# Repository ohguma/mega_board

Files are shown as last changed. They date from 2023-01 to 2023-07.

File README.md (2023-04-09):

# Arduino Mega 拡張基板

## 概要

+ Arduino Mega のA0～15をXHコネクタで使うための基板。別途下記の利用も可能。
  + 4ピンXHで［D29,D31］［D33,D35］［D37,D39］［D41,D43］
  + 他のデジタルピンもビアから接続可能。
  + 3つのスイッチ（D51,D52,D53） INPUT_PULLUPで利用する。
  + 3つのLED（D45,D47,D49）　HIGHで点灯。
  + サーボ用端子（D10～13）　電源をバッテリー直結かレギュレータ経由か切り替え可能
  + 複数のI2C端子
    + TJ3B互換［SCL,5V,SDA,GND］を2ポート
    + MPU6050用
    + [AE-BNO055-BO](https://akizukidenshi.com/catalog/g/gK-16996)
    + OLED(128x32)
+ モータードライバTB67H450FNGを最大４個搭載可能。
  + [TB67H450FNG日本語データシート](https://toshiba.semicon-storage.com/info/TB67H450FNG_datasheet_ja_20201126.pdf?did=65345&prodName=TB67H450FNG)
  + 1ch：D2,D3　2ch：D4,D5　3ch：D6,D7　4ch：D8,D9
+ 各XHコネクタへの電源は、Mega 内蔵とは別のレギュレータから供給する。ジャンパ接続で内蔵5Vも利用可能。
+ レギュレータを3.3Vに変更することで Arduino Due でも利用可能。
+ 基板サイズ　98 x 98mm、周囲の穴は3.2mm径、5mm間隔
  + [タミヤ ユニバーサルプレート](https://www.tamiya.com/japan/products/70172/index.html)上に取り付け可能。
  
----
## サンプルスケッチ

+ [sample/](./sample/)  

## マニュアル
+ [Arduino Mega 2560 基板(秋月 TB67H450FNG)マニュアル](./documents/robot_arduino_mega202210_AE-TB67H450_manual.pdf) 2022-10
+ [Arduino Mega 2560 基板(Poloru BD65496MUV)マニュアル](./documents/robot_arduino_mega202203_BD65496MUV_manual.pdf) 2022-04
  - TB67H450以前バージョン。モータードライバの配線は同様なので、同じスケッチが動作する。
  - LED1,2,3が基板パターンに実装されていないのでユニバーサル基板部分に追加すること。 
  - [BD65496MUV Single Brushed DC Motor Driver Carrier](https://www.pololu.com/product/2960)

## 実装例

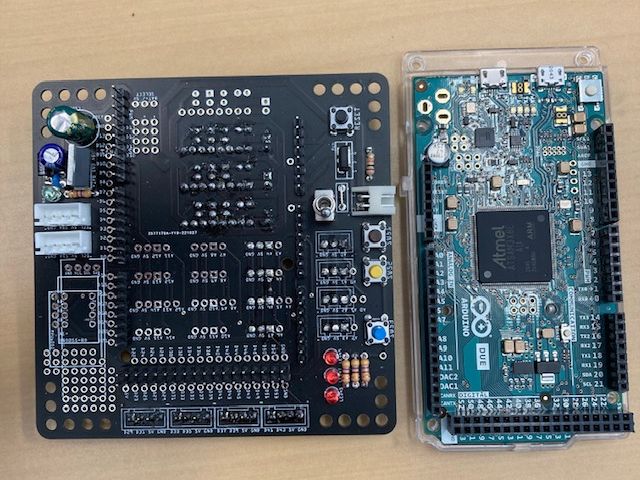
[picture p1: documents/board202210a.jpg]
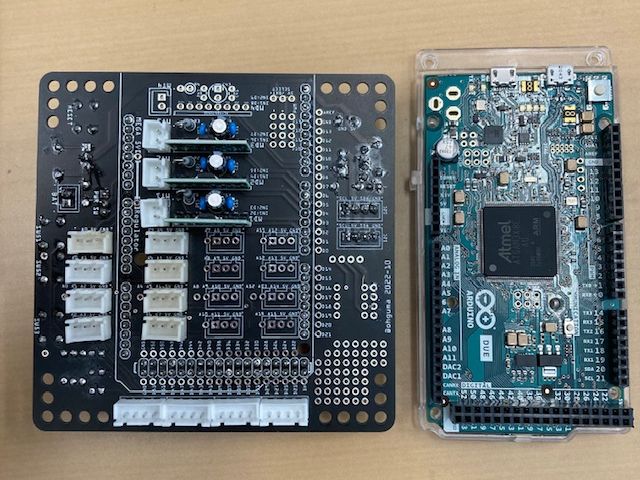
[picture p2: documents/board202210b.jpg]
　

----
### パーツリスト

個数は明記なければ1個。

+ Arduino Mega2560 R3　もしくは　Arduino Due　もしくはそれらの互換機
+ ピンヘッダ
  - 1x8　5個
  - 1x10　10個
  - 2x18　18個
  - 1x3　最大4個。サーボ使用時
+ 入出力 
  - LED45,47,49用3mmLED
  - 上記LED用電流制限抵抗 1KΩ（茶黒赤金　Vf=2[V]3mA想定）
  - タクトスイッチ　制御用　3個
  - タクトスイッチ　リセット用　1個
  - （任意）[秋月　ＢＮＯ０５５使用　９軸センサーフュージョンモジュールキット AE-BNO055-BO](https://akizukidenshi.com/catalog/g/gK-16996)
    - VIN、GND、SDA/T、SCL/Rを接続する。
  - （任意）ジャイロセンサMPU-6050
    - amazon などでMPU6050(GY-521)として売られているもの。
    - VCC、GND、SCL、SDAの4ピンを接続する。 
  - （任意）OLED 128x32 I2C
    - Adafruit SSD1306 ライブラリを利用する。

+ モータードライバ関係　最大4セット
  - [秋月　ＴＢ６７Ｈ４５０モータドライバモジュール AE-TB67H450](https://akizukidenshi.com/catalog/g/gK-14753/)
  
    - [マルツ　ブラシ付きDCモータードライバーIC DIP化基板(TB67H450FNG)](https://www.marutsu.co.jp/pc/i/1559301/)も同じピン配置なので利用できると思われる。
  - 金属皮膜抵抗 1W 0.2Ω　　抵抗値の選定はTB67H450データシート参照のこと。
  - 電解コンデンサ 50V 100uF
  - セラミックコンデンサ 0.1uF （104）
    - セラミックコンデンサのみ1セット中2個、他は1個づつ
+ 電源関連 各1個
  - 基板用トグルスイッチ（下記FETのON/OFF用）
  - PchパワーMOSFET（30V40A MTP4835I3等）
  - 抵抗 10KΩ（茶黒橙金）
  - ポリスイッチ　　短絡等の保護用。不要時はジャンパ接続する。
+ センサ系電源まわり
  - ショットキーダイオード （40V1A 1S4など。レギュレータへの逆接防止用）
  - ５Vレギュレータ（5V1A TA4805S等）　※Due使用時は3.3Vレギュレータ使用
  - セラミックコンデンサ 0.1uF （104）
  - 電解コンデンサ 50V 100uF
  - 電源ON表示用3mmLED
  - 上記LED用電流制限抵抗 1KΩ（茶黒赤金　Vf=2[V]想定で3mA）
  - 電解コンデンサ 10V 1000uF等

## 購入先

+ パーツは[秋月電子](https://akizukidenshi.com/catalog/)で概ね揃う。
+ 2023年1月21日時点、Due は[アスクル](https://www.askul.co.jp/p/KA08233/)が安い。（ピンヘッダなしが3,950円）

----
## 回路図

- モータードライバ周りはアプリケーションノートに従った。
  - [TB67H450FNGアプリケーションノート](https://akizukidenshi.com/download/ds/toshiba/TB67H450FNG_application_note_ja_20190510.pdf)

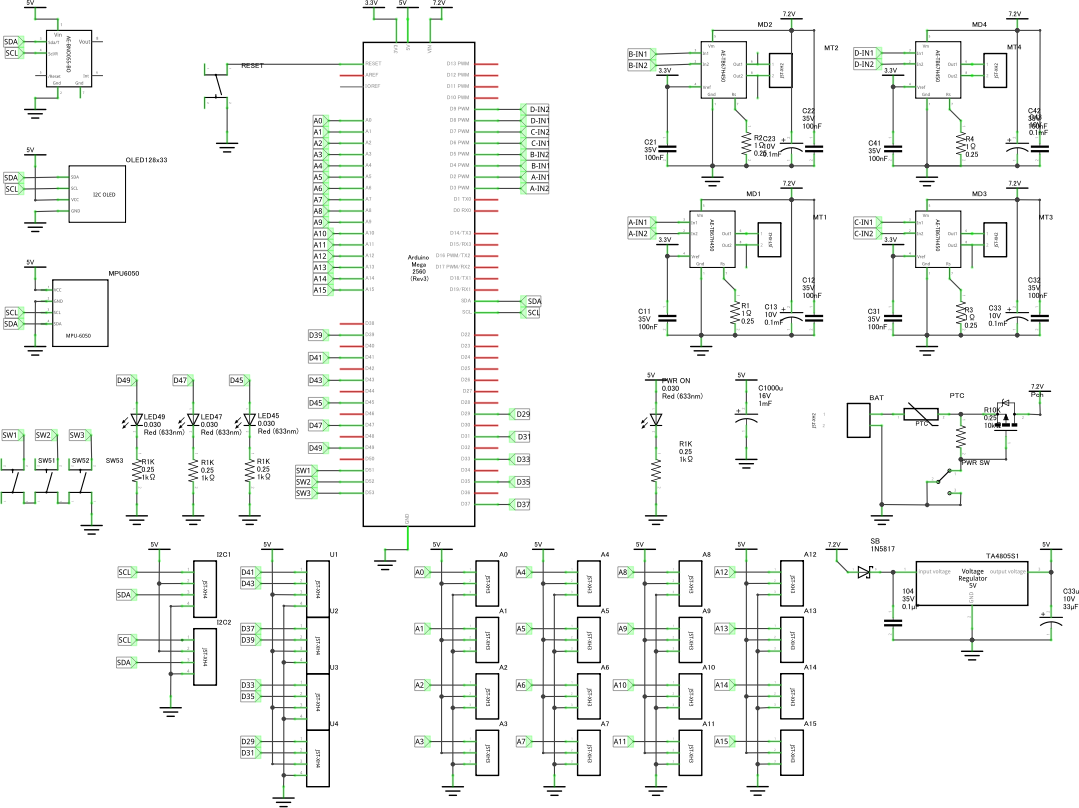
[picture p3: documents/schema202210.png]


----
## 基板作成

+ [Fritzing](https://fritzing.org/)で設計し、基板作成まで行った。
  + コネクタは表・裏どちらにも実装し易いよう、両面にシルクを入れた。（裏面はSVGを貼り付け）
  + 参考書　 「[Fritzing入門実習テキスト「Fritzing Basics」#マッハ新書 （ダウンロード商品）](https://booth.pm/ja/items/1414214)」
+ 基板作成は「[JLCPCB](https://jlcpcb.com/)」を利用した。
  + つや消し黒が安い。
  + 2022-10-27発注、2022-11-09、到着運送便はOCS Expressを選択（配達は佐川急便だった）
  + twitter https://twitter.com/JLCPCB_Japan
+ [発注時ガーバーファイル](./pcb/robot_arduino_mega202210_AE-TB67H450.zip)

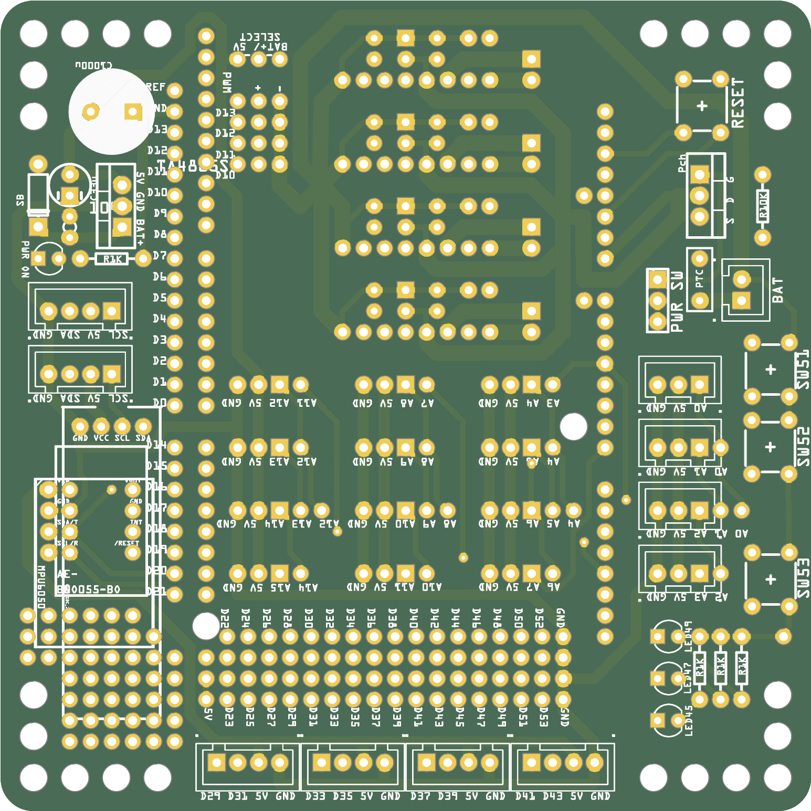
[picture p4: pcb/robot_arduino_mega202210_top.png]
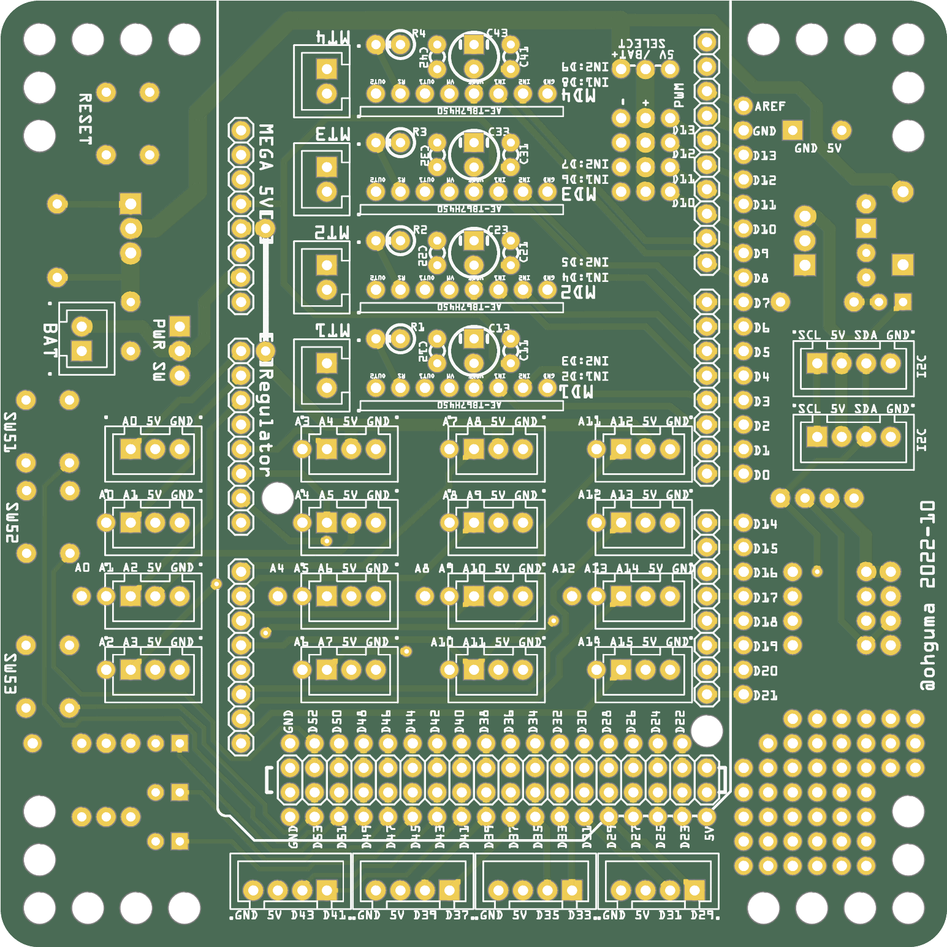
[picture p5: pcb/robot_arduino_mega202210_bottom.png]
 

----
## 3Dプリントデータ
+ [Arduino Mega 底面ホルダ](./cad/mega_bottom.stl)　※ホルダが付属しない互換機などでの利用を想定。

----

2023-04-09 ohguma 内容補足、マニュアル・サンプル追加
2023-01-21 ohguma 初版

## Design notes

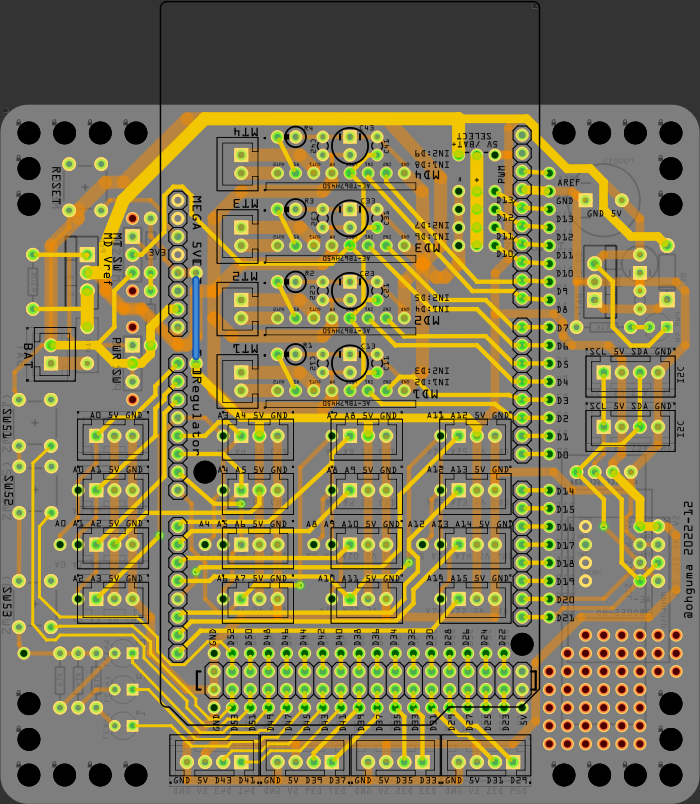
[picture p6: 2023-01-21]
documents/pcb202212b.png

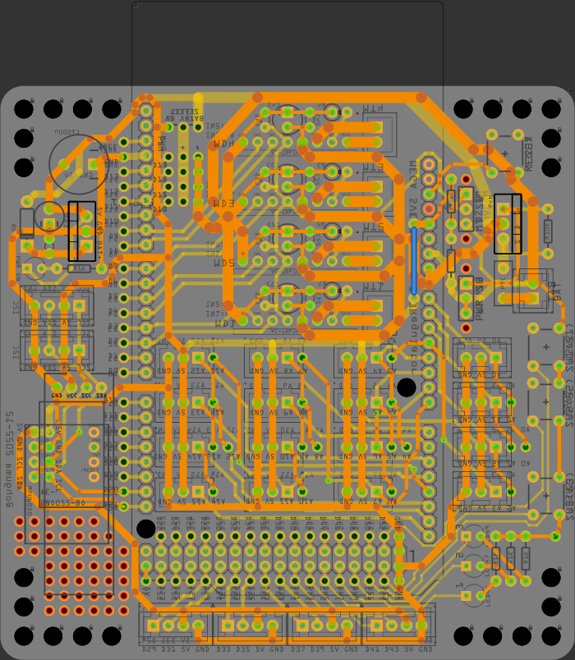
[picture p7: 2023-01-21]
documents/pcb202212a.png

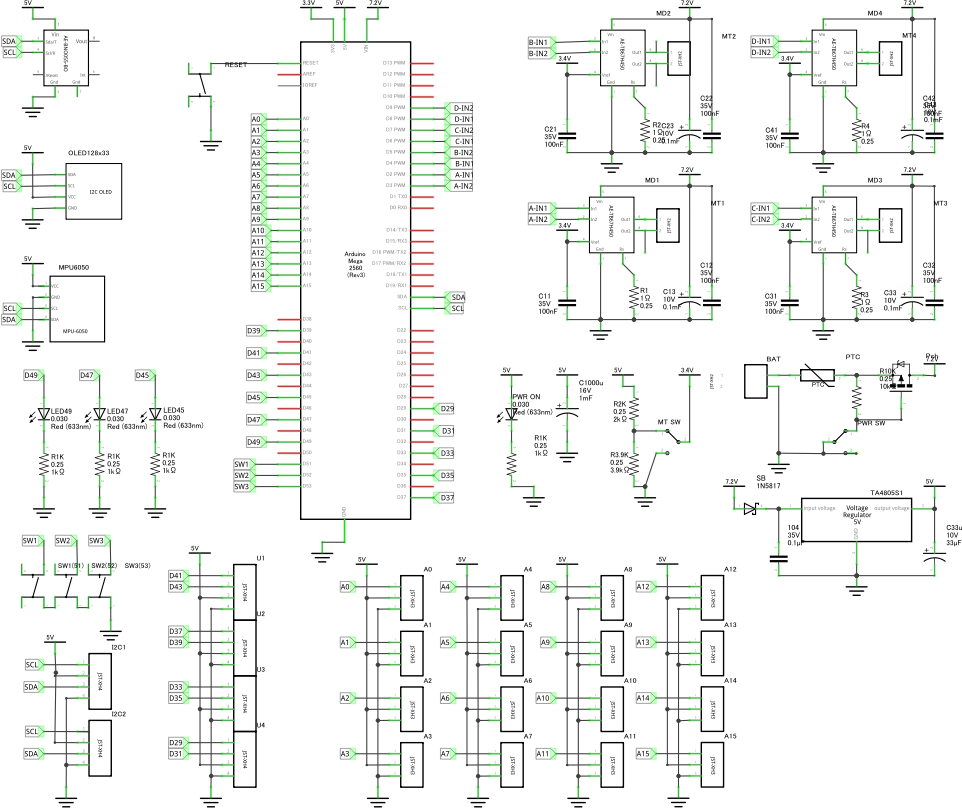
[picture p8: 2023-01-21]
documents/schema202212.png

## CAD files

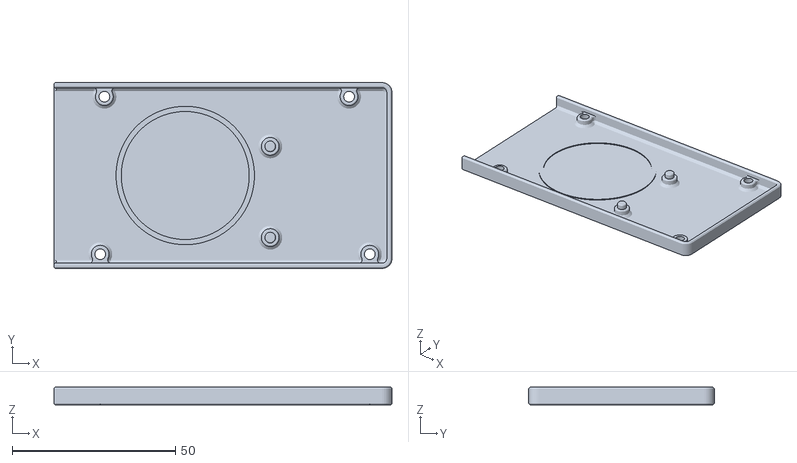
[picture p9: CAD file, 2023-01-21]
cad/mega_bottom.stl
103.5 x 56.9 x 5.40

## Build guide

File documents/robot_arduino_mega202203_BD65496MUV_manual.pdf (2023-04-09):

### ■Arduino Mega 2560 基板(Poloru BD65496MUV)

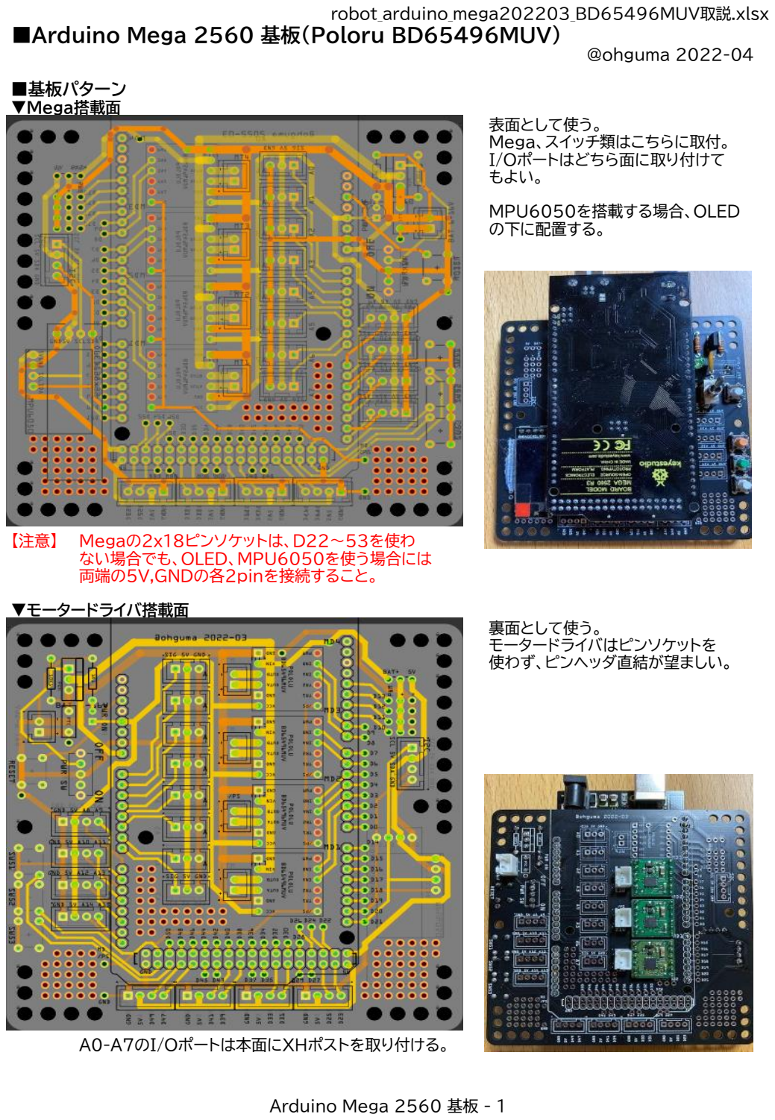
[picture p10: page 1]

robot_arduino_mega202203_BD65496MUV取説.xlsx

@ohguma 2022-04

■基板パターン
▼Mega搭載面
表面として使う。
Mega、スイッチ類はこちらに取付。
I/Oポートはどちら面に取り付けて
もよい。

MPU6050を搭載する場合、OLED
の下に配置する。

【注意】 Megaの2x18ピンソケットは、D22～53を使わ ない場合でも、OLED、MPU6050を使う場合には 両端の5V,GNDの各2pinを接続すること。

▼モータードライバ搭載面
裏面として使う。
モータードライバはピンソケットを
使わず、ピンヘッダ直結が望ましい。

A0-A7のI/Oポートは本面にXHポストを取り付ける。

Arduino Mega 2560 基板 - 1 robot_arduino_mega202203_BD65496MUV取説.xlsx ■回路図

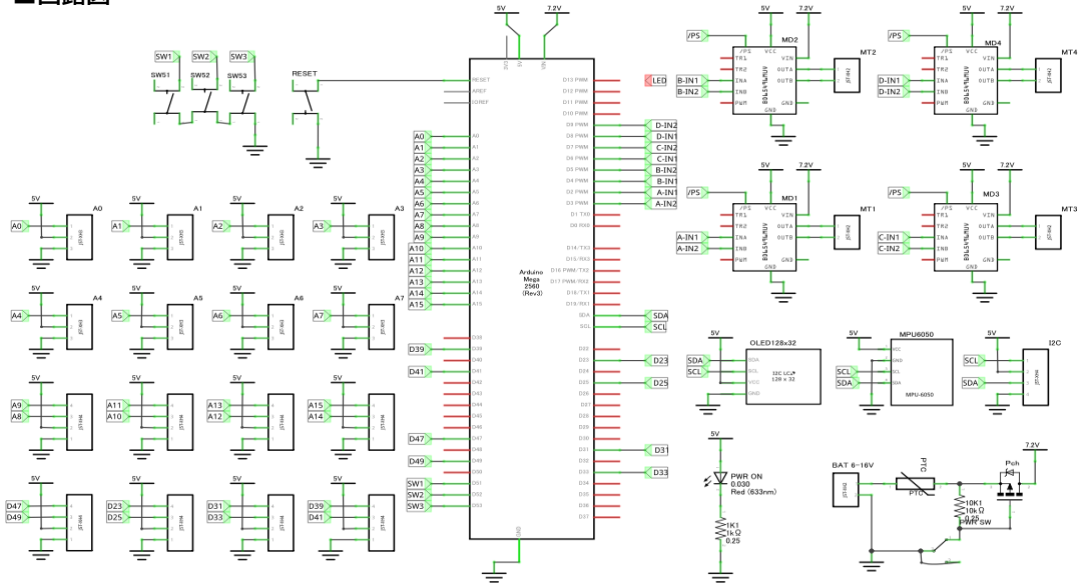
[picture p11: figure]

■パーツリスト
No | 品名 | 数量
1 | Arduino Mega2560　R3、もしくは互換機 | 1
2 | Pololu BD65496MUV Single Brushed DC Motor Driver Carrier | 最大4
3 | ジャイロセンサMPU-6050 任意 | 1
4 | OLED 128x32 I2C 任意 | 1
5 | 基板用トグルスイッチ | 1
6 | ポリスイッチ | 1
7 | PchパワーMOSFET | 1
8 | 抵抗 10KΩ | 1
9 | 電源ON表示用LED | 1
10 | その電流制限用抵抗 | 1
11 | タクトスイッチ　制御用 x3、リセット用 x1 | 4
12 | ピンヘッダ1x10 | 1
13 | ピンヘッダ1x8 | 5
14 | ピンヘッダ2x18　（D22～53を使わない場合不要だが、OLED等使用時は注意） | 1
15 | XH2ピン用ベース付ポスト 任意
16 | XH3ピン用ベース付ポスト 任意
17 | XH4ピン用ベース付ポスト 任意

■予約ピンなど
D５１ | SW51 | pinMode(５1, INPUT_PULLUP)で使う。押したときLOW
D５２ | SW52 | pinMode(５2, INPUT_PULLUP)で使う。押したときLOW
D５３ | SW53 | pinMode(５3, INPUT_PULLUP)で使う。押したときLOW
D2,3 | MD1のINA,INB
D4,5 | MD2のINA,INB
D6,7 | MD3のINA,INB
D8,9 | MD4のINA,INB

OLEDはライブラリ「Adafruit_SSD1306」の例「ssd1306_128x32_i2c」を流用

ー　以上　ー

Arduino Mega 2560 基板 - 2

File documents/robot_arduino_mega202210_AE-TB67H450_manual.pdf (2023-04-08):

### ■Arduino Mega 2560 基板(秋月 TB67H450FNG)

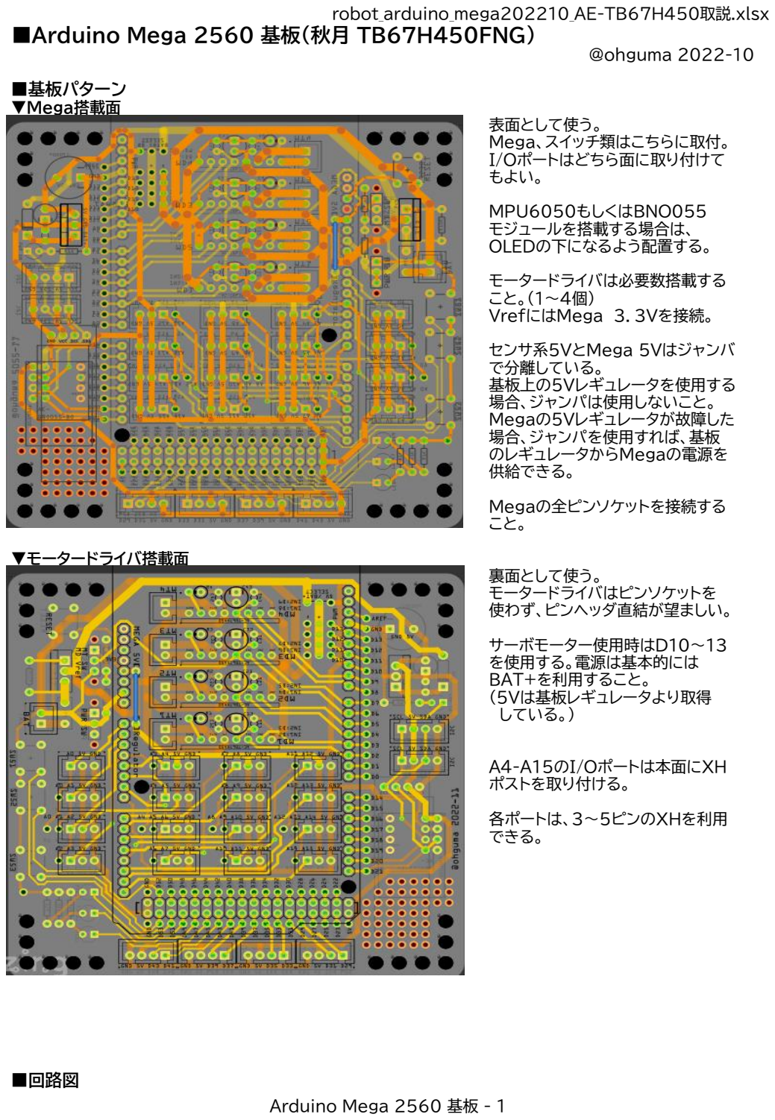
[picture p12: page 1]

robot_arduino_mega202210_AE-TB67H450取説.xlsx

@ohguma 2022-10

■基板パターン
▼Mega搭載面
表面として使う。
Mega、スイッチ類はこちらに取付。
I/Oポートはどちら面に取り付けて
もよい。

MPU6050もしくはBNO055
モジュールを搭載する場合は、
OLEDの下になるよう配置する。

モータードライバは必要数搭載する
こと。（1～4個）
VrefにはMega　３．３Vを接続。

センサ系5VとMega 5Vはジャンバ
で分離している。
基板上の5Vレギュレータを使用する
場合、ジャンパは使用しないこと。
Megaの5Vレギュレータが故障した
場合、ジャンパを使用すれば、基板
のレギュレータからMegaの電源を
供給できる。

Megaの全ピンソケットを接続する
こと。

▼モータードライバ搭載面
裏面として使う。
モータードライバはピンソケットを
使わず、ピンヘッダ直結が望ましい。

サーボモーター使用時はD10～13
を使用する。電源は基本的には
BAT+を利用すること。
(5Vは基板レギュレータより取得
している。）

A4-A15のI/Oポートは本面にXH
ポストを取り付ける。

各ポートは、３～5ピンのXHを利用
できる。

■回路図
Arduino Mega 2560 基板 - 1

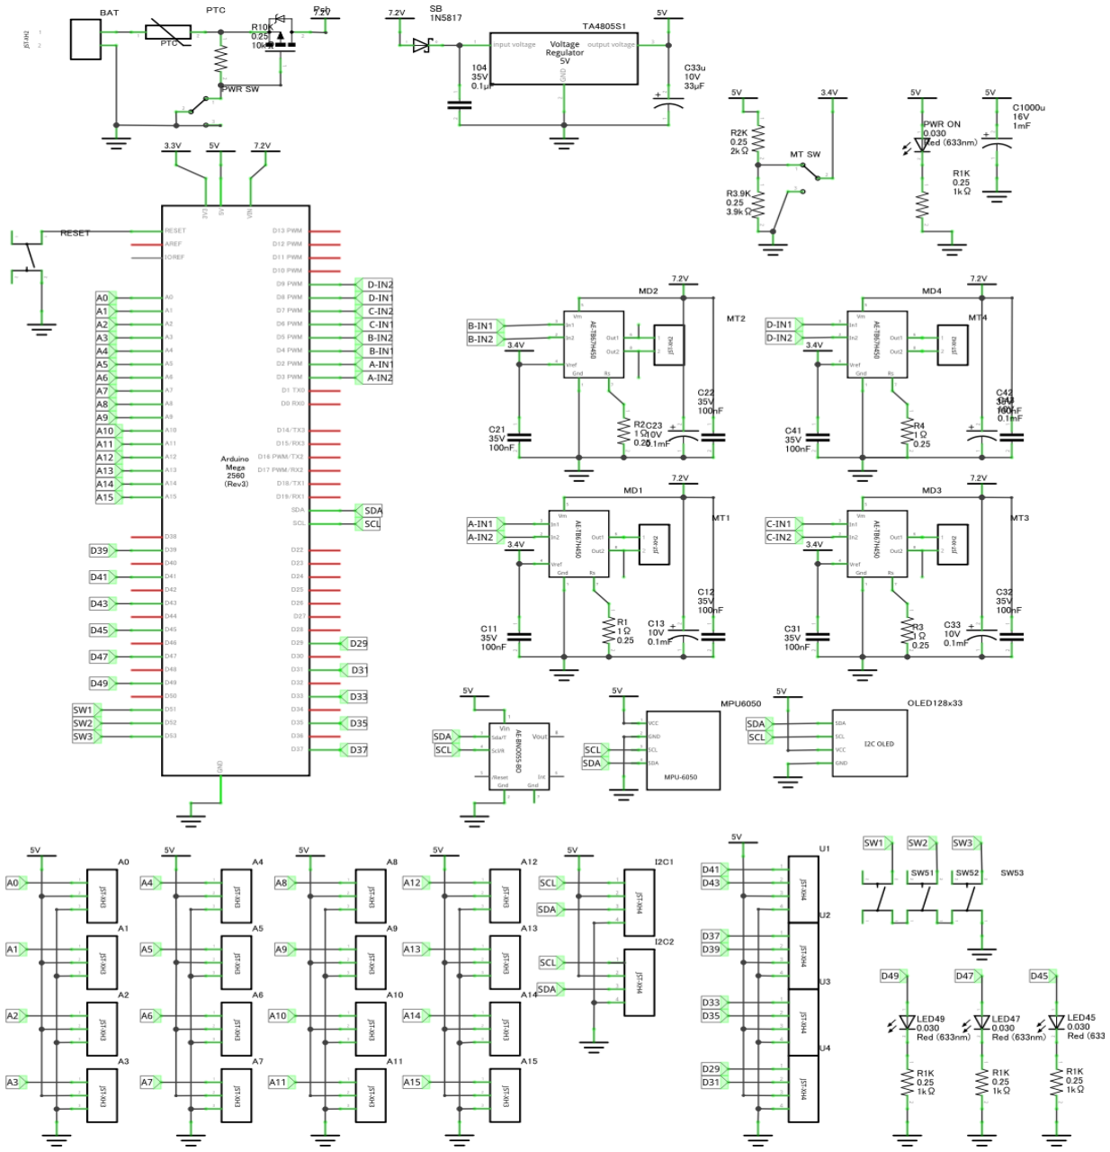
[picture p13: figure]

■パーツリスト
No | 品名 | 数量

1 | Arduino Mega2560　R3、もしくは互換機 | 1
2 | ピンヘッダ 1x8 | 5
3 | ピンヘッダ 1x10 | 1
4 | ピンヘッダ 2x18 | 1
| 【モータードライバ関係　最大4セット】
5 | 秋月　ＴＢ６７Ｈ４５０モータドライバモジュール 数量は1セットあたり | 1
6 | 金属皮膜抵抗 1W 0.2Ω | 1
7 | セラミックコンデンサ 0.1uF (104） | 2
8 | 電解コンデンサ 50V 100uF | 1
| 【センサ、表示機】　任意
9 | 秋月　ＢＮＯ０５５使用　９軸センサーフュージョンモジュールキット 任意 | 1
10 | ジャイロセンサMPU-6050 任意 | 1
11 | OLED 128x32 I2C 任意 | 1
12 | LED45,47,49用3mmLED | 3
13 | 上記LED用電流制限抵抗 1KΩ（茶黒赤金　Vf=2[V]想定で３ｍA） | 3
14 | タクトスイッチ　制御用 x3、リセット用 x1 | 4
| 【電源まわり】
15 | 基板用トグルスイッチ（下記FETのON/OFF用） | 1
16 | PchパワーMOSFET（30V40A MTP4835I3等） | 1
17 | 抵抗 10KΩ（茶黒橙金） | 1
18 | ポリスイッチ ない場合はリード線で直結 | 1
| 【センサ系電源まわり】
19 | ショットキーダイオード （４０V1A 1S4など。レギュレータへの逆接防止用） | 1
20 | ５Vレギュレータ（5V1A TA4805S等） ※DUE使用時は3.3V | 1
21 | セラミックコンデンサ 0.1uF (104） レギュレータに合わせる。入力側 | 1
22 | 電解コンデンサ 50V 100uF レギュレータに合わせる。出力側 | 1
23 | 電源ON表示用3mmLED | 1
24 | 上記LED用電流制限抵抗 1KΩ（茶黒赤金　Vf=2[V]想定で3mA） | 1
25 | 電解コンデンサ 10V 1000uF等 センサ電源の安定化用 | 1
| 【コネクタ類】
26 | XH2ピン用ベース付ポスト（バッテリ接続、モーター接続用） 任意
27 | XH3ピン用ベース付ポスト 任意
28 | XH4ピン用ベース付ポスト 任意
※レギュレータを3.3Vにする場合、LED用電流制限抵抗は470Ω等適宜調整する。

■予約ピンなど
D５１ | SW51 | pinMode(５1, INPUT_PULLUP)で使う。押したときLOW
D５２ | SW52 | pinMode(５2, INPUT_PULLUP)で使う。押したときLOW
D５３ | SW53 | pinMode(５3, INPUT_PULLUP)で使う。押したときLOW
D45 | LED45 | pinMode(45, OUTPUT)で使う。
D47 | LED47 | pinMode(47, OUTPUT)で使う。
D49 | LED49 | pinMode(49, OUTPUT)で使う。
D2,3 | MD1のINA,INB
D4,5 | MD2のINA,INB
D6,7 | MD3のINA,INB
D8,9 | MD4のINA,INB
D10～13 | サーボコネクタ用パターンあり

OLEDはライブラリ「Adafruit_SSD1306」の例「ssd1306_128x32_i2c」を流用 ー　以上　ー

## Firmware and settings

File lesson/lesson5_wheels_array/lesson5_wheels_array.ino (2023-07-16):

//----------------------------
// LESSON5：ホイールを複数回す。配列の練習
//
// 2023-07-15 ohguma 初版
//----------------------------
// Arduino Mega 拡張基板
// https://github.com/ohguma/mega_board
//
// ■ピン設定
// モータードライバ TOSHIBA TB67H450FNG
// https://toshiba.semicon-storage.com/info/TB67H450FNG_datasheet_ja_20201126.pdf?did=65345&prodName=TB67H450FNG
//   IN1   IN2   OUT1  OUT2  動作
//   ----  ----  ----  ----  -----------------
//   0     0     OFF   OFF   停止（モーター端子が接続されていない状態）
//   数値  0     ＋    －    時計回り（OUT1が電源＋、OUT2が電源－に接続される）
//   0     数値  －    ＋    反時計回り（OUT2が電源＋、OUT1が電源－に接続される）
//   数値  数値  －    －    ショートブレーキ（モーター端子を短絡した状態）
//
// ※最大4つのモータードライバは、IN1/IN2 に Arduino Mega のそれぞれ以下を
//   接続している。
//     MT1  D2/D3
//     MT2  D4/D5
//     MT3  D6/D7
//     MT4  D8/D9
//
// ※モーターの＋端子に赤線、反対側には黒線をハンダ付けし、XHコネクタには電
//   池ボックスと同じ向きに赤線・黒線を差し込むこと。
//   （コネクタの▲マークに赤線を接続する。）
//   このとき、モータードライバのOUT1にモーターの＋端子、OUT2には反対側端子
//   が接続される。
//
// ※モーターは＋端子に電池のプラス、反対側にマイナスを接続すると、ギヤを取
//   り付ける側からモーターを見た場合に、通常モーター軸が時計回りする。
//   ギヤボックスを使う場合は内部のギヤの組み合わせにより、出力軸がモーター
//   軸とは逆に回る場合がある。
//
// ※Arduino Megaでは数値はanalogWrite()の0～255で指定する。
//   0を指定した時が0%、255を指定した時が100%。
//
const int NUM_MOTOR = 2;
const int PIN_IN1[NUM_MOTOR] = { 2, 4 };
const int PIN_IN2[NUM_MOTOR] = { 3, 5 };
// タクトスイッチ
// ・SW1,SW2,SW3：D51,D52,D53かから各SWを経由してGNDに接続。
// ・INPUT_PULLUPモードで使用する。
const int PIN_SW1 = 51;

void setup() {
  setup_wheel();
  // スイッチ1 プルアップ入力設定
  pinMode(PIN_SW1, INPUT_PULLUP);
  // SW1が押されるとINPUT_PULLUPモードのdigitalRead()はLOWになる。
  while (digitalRead(PIN_SW1) == HIGH) {
    //SW1が押されていないときは少し待つ、を繰り返す
    delay(10);
  }
}

void loop() {
  int i = 0;
  int j = 0;
  // 約1秒でだんだん早くする。
  for (int j = 0; j <= 255; j++) {
    for (int i = 0; i < NUM_MOTOR; i++) {
      rotate_wheel(i, j);  // ホイール反時計回り。
    }
    delay(4);  //少し待つ。4ミリ秒
  }
  // 約1秒でだんだん遅くする。各ホイール逆回転に。

  // 停止して1秒待機
  stop_wheel_all();
  delay(1000);
}


// 複数ホイール準備
void setup_wheel() {
  for (int i = 0; i < NUM_MOTOR; i++) {
    pinMode(PIN_IN1[i], OUTPUT);
    pinMode(PIN_IN2[i], OUTPUT);
  }
}

//全ホイール停止
void stop_wheel_all() {
  for (int i = 0; i < NUM_MOTOR; i++) {
    rotate_wheel(i, 0);
  }
}

// １つのホイールを回転させる
// 引数 no  : 回すホイール番号：0の時MT1、1の時MT2、
// 引数 pwm : analogWrite()で使用するPWM値。
//            範囲は -255 <= pwm <= 255
//            ０以上で時計回り、マイナスで反時計回りとする。
void rotate_wheel(int no, int pwm) {
  if (no >= 0 && no < NUM_MOTOR) {
    if (pwm >= 0) {
      analogWrite(PIN_IN1[no], pwm);  //ピン指定は適宜調整する
      analogWrite(PIN_IN2[no], 0);
    } else {
      //alalogWrite()でセットするPWM値はプラスの値のみ
      analogWrite(PIN_IN1[no], 0);
      analogWrite(PIN_IN2[no], fabs(pwm));  // - pwm でも等価
    }
  }
}

//  ■課題
//  (1) 「Arduinoを始めよう」の「Arduino 公式リファレンス」で以下を調べる。
//    ・配列
//    ・while 文
//
//  (2) コメント「 // 約1秒でだんだん遅くする。各ホイール逆回転に。」の箇所
//      を補足する。
//
//  (3) 接続している全ホイールを動かす。
//
//  (4) 関数 setup_wheel()、rotate_wheel()、stop_wheel_all() の定義部分と、
//      そこで使用するピン指定を別ファイルに分割してみること。
//        [ヒント] 別ファイル内で自作関数を使用する場合、使用する箇所よりも
//                 先にその関定義されている必要がある。
//

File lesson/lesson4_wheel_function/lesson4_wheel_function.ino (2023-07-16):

//----------------------------
// LESSON4：ホイールを1つ回す。関数の練習
//
// 2023-07-13 ohguma 初版
//----------------------------
// Arduino Mega 拡張基板
// https://github.com/ohguma/mega_board
//
// ■ピン設定
// モータードライバ TOSHIBA TB67H450FNG
// https://toshiba.semicon-storage.com/info/TB67H450FNG_datasheet_ja_20201126.pdf?did=65345&prodName=TB67H450FNG
//   IN1   IN2   OUT1  OUT2  動作
//   ----  ----  ----  ----  -----------------
//   0     0     OFF   OFF   停止（モーター端子が接続されていない状態）
//   数値  0     ＋    －    時計回り（OUT1が電源＋、OUT2が電源－に接続される）
//   0     数値  －    ＋    反時計回り（OUT2が電源＋、OUT1が電源－に接続される）
//   数値  数値  －    －    ショートブレーキ（モーター端子を短絡した状態）
//
// ※最大4つのモータードライバは、IN1/IN2 に Arduino Mega のそれぞれ以下を
//   接続している。
//     MT1  D2/D3
//     MT2  D4/D5
//     MT3  D6/D7
//     MT4  D8/D9
//
// ※モーターの＋端子に赤線、反対側には黒線をハンダ付けし、XHコネクタには電
//   池ボックスと同じ向きに赤線・黒線を差し込むこと。
//   （コネクタの▲マークに赤線を接続する。）
//   このとき、モータードライバのOUT1にモーターの＋端子、OUT2には反対側端子
//   が接続される。
//
// ※モーターは＋端子に電池のプラス、反対側にマイナスを接続すると、ギヤを取
//   り付ける側からモーターを見た場合に、通常モーター軸が時計回りする。
//   ギヤボックスを使う場合は内部のギヤの組み合わせにより、出力軸がモーター
//   軸とは逆に回る場合がある。
//
// ※Arduino Megaでは数値はanalogWrite()の0～255で指定する。
//   0を指定した時が0%、255を指定した時が100%。
//
// MT1を使用する場合は、MegaのD2,D3を使用する。
const int PIN_IN1 = 2;
const int PIN_IN2 = 3;

void setup() {
  setup_wheel();
}

void loop() {
  int j = 0;
  // ホイール時計回り。約1秒でだんだん早くする。
  for (j = 0; j <= 255; j++) {
    rotate_wheel(j);
    delay(4);  //少し待つ。4ミリ秒
  }
  // ホイール時計回り。約1秒でだんだん遅くする。

  // ホイール反時計回り。約1秒でだんだん早くする。

  // ホイール反時計回り。約1秒でだんだん遅くする。

  // 停止して1秒待機
  rotate_wheel(0);
  delay(1000);
}


// ホイール準備
void setup_wheel() {
  pinMode(PIN_IN1, OUTPUT);
  pinMode(PIN_IN2, OUTPUT);
}

// ホイールを回転させる
// 引数 pwm : analogWrite()で使用するPWM値。
//            範囲は -255 <= pwm <= 255
//            ０以上で時計回り、マイナスで反時計回りとする。
void rotate_wheel(int pwm) {
  if (pwm >= 0) {
    analogWrite(PIN_IN1, pwm);  //ピン指定は適宜調整する
    analogWrite(PIN_IN2, 0);
  } else {
    //alalogWrite()でセットするPWM値はプラスの値のみ
    analogWrite(PIN_IN1, 0);
    analogWrite(PIN_IN2, fabs(pwm)); // - pwm でも等価
  }
}

//  ■課題
//  (1) 「Arduinoを始めよう」の「Arduino 公式リファレンス」で以下を調べる。
//    ・for 文
//    ・analogWrite()
//    ・関数
//    ・map()
//    ・constrain()
//    ・#include
//
//  (2) 先のLESSON3と同じようにモーターが動作するよう loop() 内で下記のコメ
//      ント箇所を補足する。
//        ・モーター軸時計回り。約1秒でだんだん遅くする。
//        ・モーター軸反時計回り。約1秒でだんだん早くする。
//        ・モーター軸反時計回り。約1秒でだんだん遅くする。
//
// (3) 関数 rotate_wheel() の引数をパーセントで指定するよう修正する。
//     その際、loop() 中で rotate_wheel() を呼び出す for 文や、for 文中の
//     delay() で指定する値も修正すること。
//       [ヒント] rotate_wheel() 内で、-100～100で指定された引数の値を
//                map() で -255～255の範囲の値に変換して analogWrite() で使
//                用する。
//       [ヒント] -100～100の範囲外の値が指定された場合でも問題が起きないよ
//                うに constrain() を使用して下記の安全対策を取っておくこと。
//                ・-100より小さい場合は、-100が指定されたことにする。
//                ・100より大きい場合は、100が指定されたことにする。
//
//     ※Arduino Megaでは数値はanalogWrite()の0～255(8bit)で指定するが、別の
//       マイコンでは0～1023(10bit)や0～4095(12bit)で指定することもある。
//       パーセント指定で関数を呼ぶようにしておけば、マイコンを切り替えた時
//       でも、loop() 側のメイン処理はそのままで、関数側の変換内容を修正する
//       だけで対応できる。
//
// (4) 関数 setup_wheel() と rotate_wheel() の定義部分と、そこで使用するピン
//     指定を別ファイルに分割してみること。コメントも適宜移動する。
//     Arduino IDE で今開いているスケッチに新しいタブを追加し、ファイル名を
//     wheel.h とする場合、今のスケッチの冒頭に下記を記載すると、別ファイル
//     の内容を今のスケッチに取り入れることができる。
//         #include "wheel.h"
//
//     ※#includeの文末にはセミコロン不要。
//
//     ※プログラムの再利用や管理が容易になる上に、メインスケッチの見通しも
//       良くなるので機能ごとにファイルを分割しておくことを勧める。
//

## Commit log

2023-01-21 初回登録
    [mega_bottom.stl, robot_arduino_mega202210_AE-TB67H450.fzz, robot_arduino_mega202212_AE-TB67H450.fzz]
2023-01-21 モータードライバ情報追加、3Dプリントデータ追加など
2023-04-08 マニュアル・サンプル追加
2023-04-09 BD65496MUV版の記載追加
2023-04-09 モーター動作のサンプル追加
2023-07-10 feature:LESSON1,2の新規追加
2023-07-12 fix:lesson2 課題の修正
2023-07-13 LESSON4追加。関数について
2023-07-16 LESSON4コメント修正
2023-07-16 LESSON5追加 配列について
2023-07-23 誤登録したファイルの削除
